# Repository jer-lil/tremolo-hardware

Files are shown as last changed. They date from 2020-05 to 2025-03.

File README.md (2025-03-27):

This is the hardware (PCB, MCAD) design for a tremolo pedal for guitar (or bass, synth, tonewheel organ, whatever you like). 
The firmware is here: https://github.com/jer-lil/tremolo-firmware/tree/main

This tremolo packs a lot of features into a very small (Hammond 125B, 65x120mm) enclosure.
Features include:

- All analog signal path
- Full stereo, with dedicated 1/4" jacks
- Harmonic tremolo
  - Continually adjustable LFO phase, allowing for sounds between mono/stereo/harmonic not found in other tremolo pedals (that I've discovered, please let me know if you know of any)
- Envelope control
  - The louder you play, the faster the tremolo goes. Or slower. Or stronger. Or the triangle wave warps towards a sawtooth. You decide.
- Expression pedal control
- Tap Tempo
  - Optional external tap signal
- "Ramp" mode, allowing user to ramp the rate up or down using a footswitch
- MIDI control

Note that at the time of writing, this project is still in progress.
As such, I have not been focusing on public documentation. If you have questions, please reach out.

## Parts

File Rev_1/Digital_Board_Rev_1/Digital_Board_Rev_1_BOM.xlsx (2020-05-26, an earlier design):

Id | Designator | Package | MPN | Quantity | Designation | Supplier and ref | _1
1 | J1 | MF_Connectors-MICROUSB-RIGHT |  | 1 | USB_MICRO_RIGHT
2 | U1 | MF_IC_Digital-SSOP16 |  | 1 | FT230XS-R
3 | REF**,REF**,C12,C21,C20,C19,C18,C17,C16,C14,C13,C9,C8,C7,C3,C2 | MF_Passives-C0402 |  | 16 | 0.1uF
4 | GND | MF_Connectors-PTH_2.54MM_01X02 |  | 1 | VAL**
5 | DEPTH,TRIM,SUBDIV,OFFSET,SHAPE,RATE | MF_Passives-TC33 | TC33X-2-103E | 6 | POTENTIOMETER_10K_TC33
6 | JP8,JP7,JP6,JP5,JP4,JP3,JP2,JP1,JP14,JP13,JP12,JP11,JP10,JP9 | SolderJumper-2_P1.3mm_Bridged_Pad1.0x1.5mm |  | 14 | SolderJumper_2_Bridged
7 | J22,J13,SW1,SW2,J17,PWM | MF_Connectors-PTH_2.54MM_01X02 |  | 6 | CON_01X02_PTH_2.54MM
8 | H4,H3,H2,H1 | MountingHole_3.2mm_M3 |  | 4 | MountingHole_Pad
9 | C24,C23,C22,C15 | MF_Passives-C0402 |  | 4 | 100n
10 | J21 | BarrelJack_CUI_PJ-063AH_Horizontal_CircularHoles |  | 1 | Barrel_Jack
11 | U15,U14 | SOP-4_3.8x4.1mm_P2.54mm |  | 2 | CPC1017N
12 | J20 | Jack_0.25in_TRS_Switched |  | 1 | AudioJack3_Switch
13 | U13 | LQFP-64_10x10mm_P0.5mm | STM32F030RCT6TR | 1 | STM32F030RCTx
14 | U12,U11,U8,U7 | Luna_NSL-32 |  | 4 | NSL-32
15 | U10,U9,U6,U5 | MF_Discrete_Semiconductor-SOT-23-3 |  | 4 | NPN_BJTMMBT3904_SOT-23-3
16 | U4,U3 | TSSOP-14-1EP_4.4x5mm_P0.65mm |  | 2 | MCP42050
17 | U2 | MF_IC_Power-SOT-223-3 |  | 1 | NCP1117LPST33T3G
18 | RESET | MF_Switches-TACT4.2MM |  | 1 | TACT_4.2MM
19 | BYPASS,TAP | MF_Switches-TACT6MM |  | 2 | TACT_6MM
20 | SW2 | SW_DIP_SPSTx02_Slide_9.78x7.26mm_W7.62mm_P2.54mm |  | 1 | SW_DIP_x02
21 | SW1 | SW_DIP_SPSTx04_Slide_9.78x12.34mm_W7.62mm_P2.54mm |  | 1 | SW_DIP_x04
22 | RV6,RV5,RV4,RV3,RV2,RV1 | Potentiometer_Alpha_RD901F-40-00D_Single_Vertical_CircularHoles |  | 6 | 10k
23 | R29,R28 | MF_Passives-R0402 |  | 2 | 47
24 | R27,R26,R25 | MF_Passives-R0402 |  | 3 | 100
25 | R18 | MF_Passives-R0603 |  | 1 | 0
26 | R17 | MF_Passives-R0402 |  | 1 | 10k
27 | R16,R15,R10,R9 | MF_Passives-R0603 |  | 4 | 10k
28 | R14,R13,R12,R11,R8,R7,R6,R5 | MF_Passives-R0603 |  | 8 | 100
29 | R4 | MF_Passives-R0402 |  | 1 | 470
30 | R3,R2 | MF_Passives-R0402 |  | 2 | 330
31 | R1 | MF_Passives-R0402 |  | 1 | 560
32 | GPIO,SWD,UART | MF_Connectors-PTH_2.54MM_01X06 |  | 3 | CON_01X06_PTH_2.54MM
33 | J14 | MF_Connectors-PTH_2.54MM_01X04 |  | 1 | CON_01X04_PTH_2.54MM
34 | AIN,Digipot_2_1,Digipot_2_0,Digipot_1_1,Digipot_1_0 | MF_Connectors-PTH_2.54MM_01X03 |  | 5 | CON_01X03_PTH_2.54MM
35 | J9,J8,J7,J6 | MF_Connectors-PTH_2.54MM_01X02 |  | 4 | Conn_01x02_Male
36 | D13,D1 | MF_Discrete_Semiconductor-SMA |  | 2 | DIODES_B140_SMA
37 | LED2,D9,D8,D7,D6 | MF_LEDs-LED0805 |  | 5 | LED_SINGLE-0805-RED
38 | LED1 | MF_LEDs-LED0805 |  | 1 | LED_SINGLE-0805-GREEN
39 | D10 | MF_LEDs-PLCC4 |  | 1 | LED_RGB_CA_PLCC4
40 | 3V3,D4,D3,VIN | MF_LEDs-LED0603 |  | 4 | LED_SINGLE-0603-GREEN
41 | C11,C1 | MF_Passives-C0402 |  | 2 | 1uF
42 | C10 | MF_Passives-C0402 |  | 1 | 10n
43 | C6,C5,C4 | MF_Passives-C1206 |  | 3 | 10uF

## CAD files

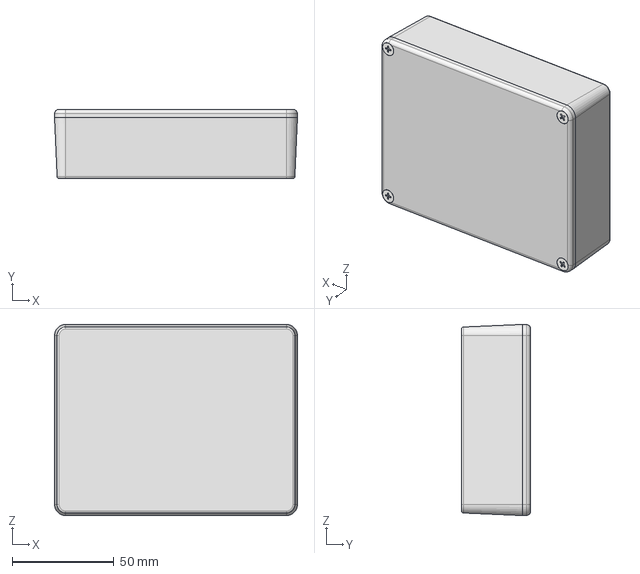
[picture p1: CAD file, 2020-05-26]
3D_Models/1590BB.stp
119.5 x 34.0 x 94.0 mm

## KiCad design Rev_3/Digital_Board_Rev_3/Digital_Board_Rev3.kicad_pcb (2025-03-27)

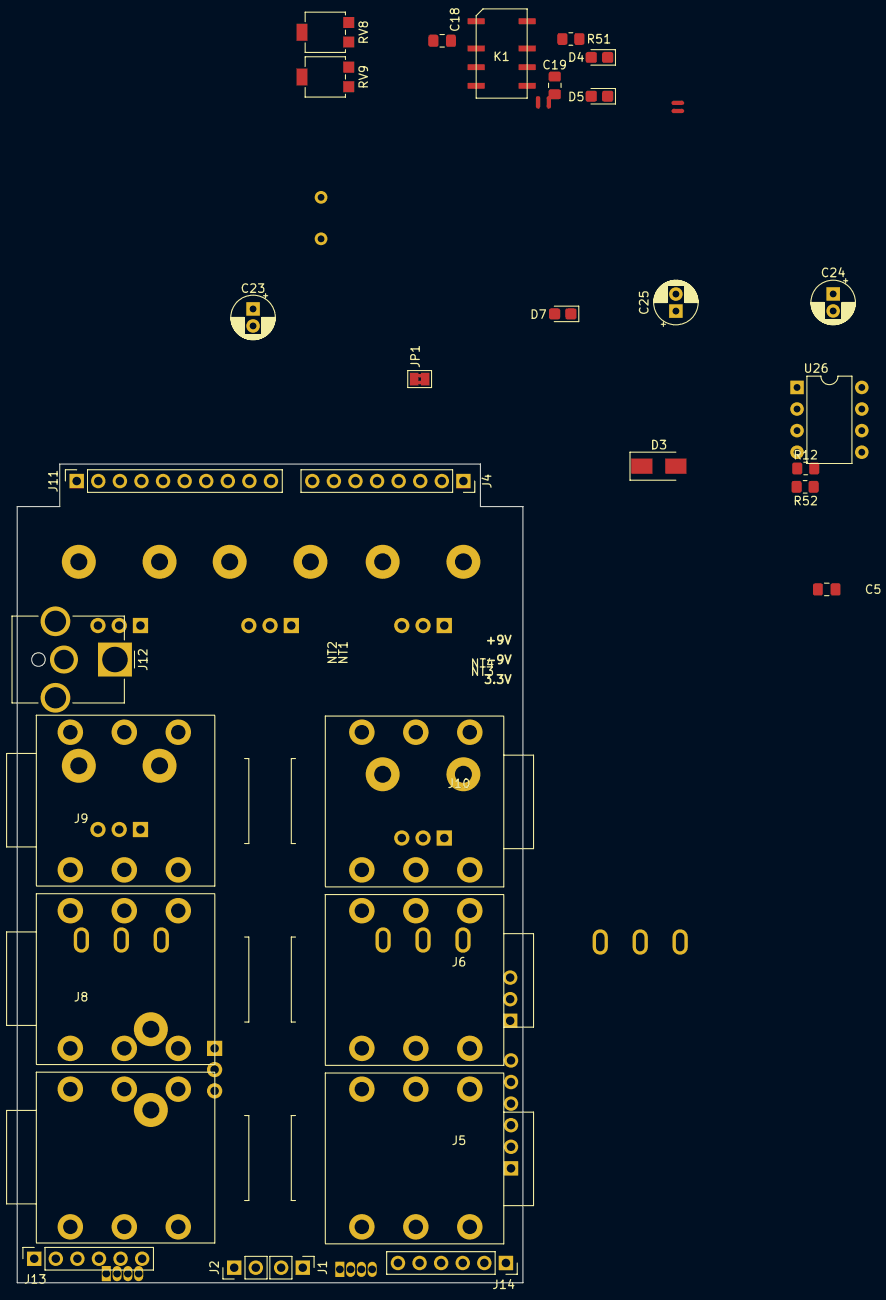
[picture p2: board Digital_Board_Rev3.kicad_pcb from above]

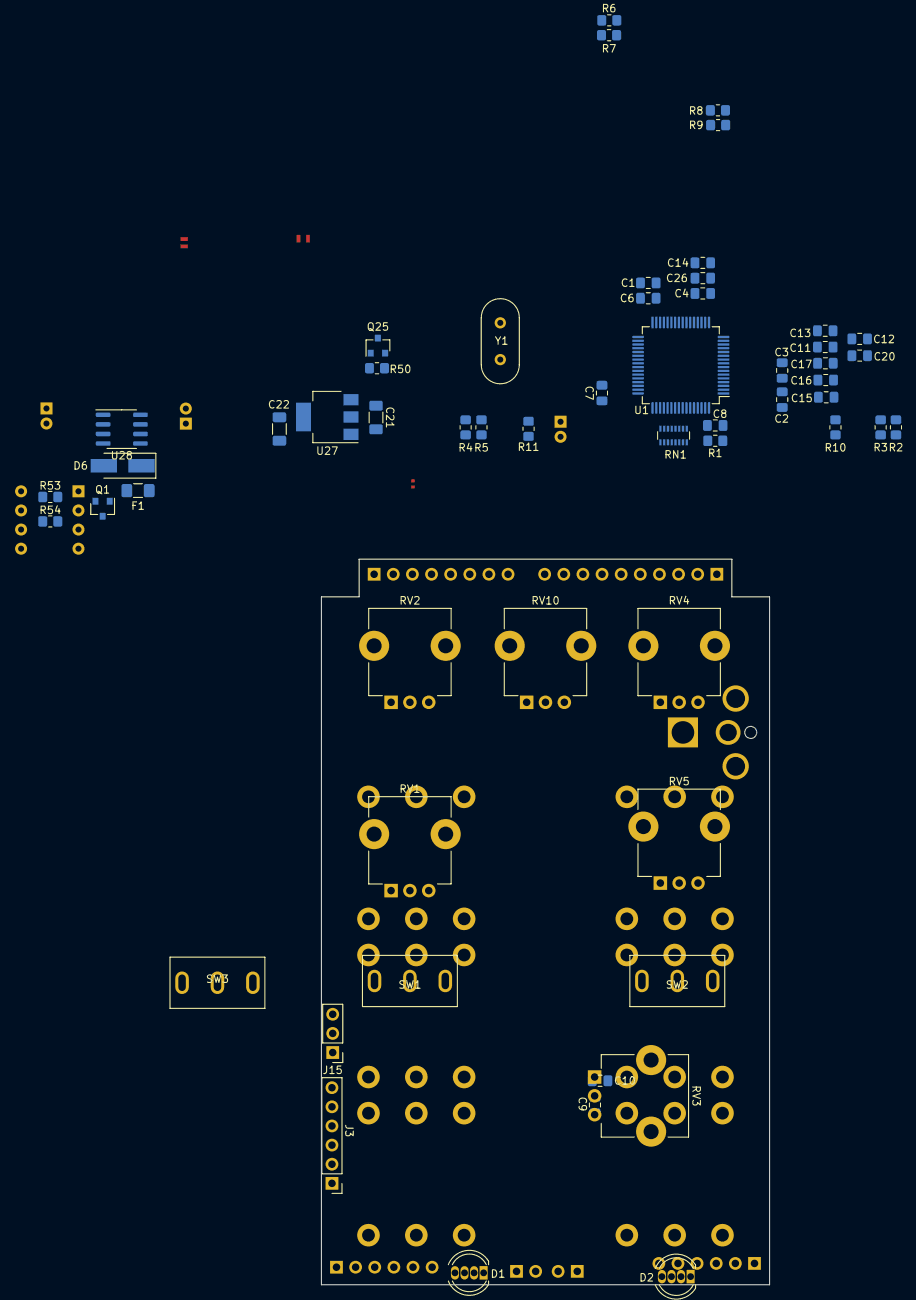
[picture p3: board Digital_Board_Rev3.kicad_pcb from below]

Board: 4 copper layers, 59.5 x 96.3 mm, 91 parts (56 on the bottom side), 94 nets, no tracks yet.

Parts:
C1: 4.7u; C_0805_2012Metric_Pad1.18x1.45mm_HandSolder
C2, C3: 18p; C_0805_2012Metric_Pad1.18x1.45mm_HandSolder
C4, C5, C6, C7, C8, C16, C17, C20: 100n; C_0805_2012Metric_Pad1.18x1.45mm_HandSolder
C9: 10n; C_0805_2012Metric_Pad1.18x1.45mm_HandSolder
C10: 1u; C_0805_2012Metric_Pad1.18x1.45mm_HandSolder
C11, C12, C13, C14, C15, C26: 100nF; C_0805_2012Metric_Pad1.18x1.45mm_HandSolder
C18, C19: 470n; C_0805_2012Metric_Pad1.18x1.45mm_HandSolder
C21, C22: 10u; C_1206_3216Metric_Pad1.33x1.80mm_HandSolder
C23, C24, C25: 100uF; CP_Radial_D5.0mm_P2.00mm
D1, D2: LED_RGBA; LED_D5.0mm-4_RGB
D3: B120-E3; D_SMA
D4, D5, D7: LED_Small; LED_0805_2012Metric_Castellated
D6: D_Zener; D_SMA_Handsoldering
F1: Polyfuse; Fuse_1206_3216Metric_Pad1.42x1.75mm_HandSolder
J1, J2: Conn_01x02_Male; PinHeader_1x02_P2.54mm_Vertical
J3: Conn_01x06_Male; PinHeader_1x06_P2.54mm_Vertical
J4: Conn_01x08_Female; PinSocket_1x08_P2.54mm_Vertical
J5, J6, J7, J8, J9, J10: AudioJack3_Switch; Jack_0.25in_TRS_Switched
J11: Conn_01x10_Female; PinSocket_1x10_P2.54mm_Vertical
J12: Barrel_Jack; BarrelJack_CUI_PJ-063AH_Horizontal_CircularHoles
J13, J14: Conn_01x06_Female; PinSocket_1x06_P2.54mm_Vertical
J15: Conn_01x03_Male; PinHeader_1x03_P2.54mm_Vertical
JP1: Jumper; SolderJumper-2_P1.3mm_Bridged2Bar_Pad1.0x1.5mm
K1: IM05; Relay_DPDT_NL_TE_IM05GR
NT1, NT2, NT3, NT4: Net-Tie_2; NetTie-2_SMD_Pad0.5mm
Q1: BSS83P; SOT-23
Q25: MMBT3904; SOT-23
R1, R8: 10k; R_0805_2012Metric_Pad1.20x1.40mm_HandSolder
R2, R3, R4, R5, R10, R11: 330; R_0805_2012Metric_Pad1.20x1.40mm_HandSolder
R6, R7, R12, R51: 1k; R_0805_2012Metric_Pad1.20x1.40mm_HandSolder
R9: 19.1k; R_0805_2012Metric_Pad1.20x1.40mm_HandSolder
R50: 2.2k; R_0805_2012Metric_Pad1.20x1.40mm_HandSolder
R52: 470; R_0805_2012Metric_Pad1.20x1.40mm_HandSolder
R53, R54: 630; R_0805_2012Metric_Pad1.20x1.40mm_HandSolder
RN1: R_Pack08; R_Array_Convex_8x0602
RV1, RV2, RV3, RV4, RV5, RV10: R_POT_TRIM; Potentiometer_9MM
RV8, RV9: 100k; Potentiometer_Bourns_3314G_Vertical
SW1, SW2, SW3: SW_SPDT_MSM; SW_Toggle_SPDT
U1: STM32F303R6Tx; LQFP-64_10x10mm_P0.5mm
U26: TLP222A-2; DIP-8_W7.62mm
U27: NCP1117-3.3_SOT223; SOT-223-3_TabPin2
U28: TC7662Bx0A; SOIC-8_3.9x4.9mm_P1.27mm
Y1: 8MHz; Crystal_HC49-U_Vertical

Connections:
+3V3: C1.1, C4.1, C6.1, C7.1, C8.1, C9.1, C10.1, C22.1, D1.4, D2.4, J3.1, J9.R, J11.9, R6.2, R52.1, RV1.3, RV2.3, RV3.3, RV4.3, RV5.3, RV10.3, U1.13, U1.19, U1.32, U1.48, U1.64, U27.2
+9V: C21.1, C23.1, D3.1, D6.1, F1.1, J4.7, K1.1, R51.1, U27.3, U28.1, U28.8
-9V: C25.2, J4.4, R12.2, U28.5
/Audio Jacks/CH1_OUT: J8.T, RV8.2
/Audio Jacks/CH1_OUT_PRE: C18.1, RV8.1, U26.8
/Audio Jacks/CH2_OUT: J7.T, RV9.2
/Audio Jacks/CH2_OUT_PRE: C19.1, RV9.1, U26.6
/BYP: J1.2, U1.44
/CH1_BYP: J11.2, K1.2
/CH1_EFF: J11.3, K1.4
/CH1_IN: J5.T, J6.TN, J11.1
/CH1_SW: J5.SN, U1.51
/CH2_BYP: J4.2, K1.7
/CH2_EFF: J4.3, K1.5
/CH2_IN: J4.1, J6.T
/CH2_SW: J6.SN, U1.52
/DEPTH: C12.1, RV2.2, U1.15
/DIP1: J11.8, U1.26
/DIP2: J11.7, U1.27
/DIP3: J11.6, U1.28
/DIP4: J11.5, U1.43
/ENV_MODE_1: SW3.3, U1.34
/ENV_MODE_2: SW3.1, U1.35
/EXP: C16.1, R8.2, R9.1, U1.9
/EXP_SW: J9.SN, U1.42
/HARM_MODE_1: SW1.3, U1.62
/HARM_MODE_2: SW1.1, U1.29
/LED1_B: RN1.6, U1.53
/LED1_G: RN1.5, U1.54
/LED1_R: RN1.4, U1.56
/LED2_B: RN1.3, U1.57
/LED2_G: RN1.2, U1.58
/LED2_R: RN1.1, U1.59
/LEDs/B1_R: D1.3, RN1.11
/LEDs/B2_R: D2.3, RN1.14
/LEDs/G1_R: D1.2, RN1.12
/LEDs/G2_R: D2.2, RN1.15
/LEDs/R1_R: D1.1, RN1.13
/LEDs/R2_R: D2.1, RN1.16
/MUTE1: R53.2, U1.2
/MUTE2: R54.2, U1.3
/NRST: C5.1, J3.5, U1.7
/OFFSET: C14.1, RV4.2, U1.17
/OSC1: C2.2, U1.5, Y1.2
/OSC2: C3.2, U1.6, Y1.1
/PAN_MODE_1: SW2.3, U1.30
/PAN_MODE_2: SW2.1, U1.33
/PWM1: R2.1, U1.22
/PWM2: R3.1, U1.20
/PWM3: R4.1, U1.39
/PWM4: R5.1, U1.40
/PWM_OUT_1: J13.1, R2.2
/PWM_OUT_2: J13.3, R3.2
/PWM_OUT_3: J14.2, R4.2
/PWM_OUT_4: J14.4, R5.2
/PWM_OUT_VOL_1: J13.5, R10.2
/PWM_OUT_VOL_2: J14.6, R11.2
/PWM_RTN_1: J13.2, NT1.1
/PWM_RTN_2: J13.4, NT2.1
/PWM_RTN_3: J14.1, NT3.1
/PWM_RTN_4: J14.3, NT4.1
/PWM_VOL_1: R10.1, U1.21
/PWM_VOL_2: R11.1, U1.55
/RATE: C11.1, RV1.2, U1.14
/RLY_SET: R50.2, U1.50
/SHAPE: C13.1, RV3.2, U1.16
/SUBDIV: C15.1, RV5.2, U1.8
/SWCLK: J3.2, U1.49
/SWDIO: J3.4, U1.46
/TAP: J2.2, U1.45
/TAP_EXT: R7.2, U1.37
/TRIM1: C17.1, J4.6, U1.10
/TRIM2: C20.1, J4.5, U1.11
/UART_RX: J15.2, U1.25
/UART_TX: J15.3, U1.24
/VOL: C26.1, RV10.2, U1.23
GNDA: J4.8, J5.S, J6.S, J7.S, J8.S, J11.10, JP1.2, RV8.3, RV9.3, U26.5, U26.7
GNDD: C1.2, C2.1, C3.1, C4.2, C5.2, C6.2, C7.2, C8.2, C9.2, C10.2, C11.2, C12.2, C13.2, C14.2, C15.2, C16.2, C17.2, C20.2, C21.2, C22.2, C23.2, C25.1, C26.2, D4.1, D5.1, D6.2, D7.2, J1.1, J2.1, J3.3, J9.S, J11.4, J12.2, J15.1, JP1.1, NT1.2, NT2.2, NT3.2, NT4.2, Q1.1, Q25.2, R1.1, R9.2, RV1.1, RV2.1, RV3.1, RV4.1, RV5.1, RV10.1, SW1.2, SW2.2, SW3.2, U1.12, U1.18, U1.31, U1.47, U1.63, U26.2, U26.4, U27.1, U28.3
unnamed: C18.2, K1.3
unnamed: C19.2, K1.6
unnamed: C24.1, U28.2
unnamed: C24.2, U28.4
unnamed: D3.2, K1.8, Q25.3
unnamed: D4.2, R51.2
unnamed: D5.2, R52.2
unnamed: D7.1, R12.1
unnamed: F1.2, Q1.2
unnamed: J9.T, R8.1
unnamed: J10.T, R6.1, R7.1
unnamed: J12.1, Q1.3
unnamed: Q25.1, R50.1
unnamed: R1.2, U1.60
unnamed: R53.1, U26.1
unnamed: R54.1, U26.3

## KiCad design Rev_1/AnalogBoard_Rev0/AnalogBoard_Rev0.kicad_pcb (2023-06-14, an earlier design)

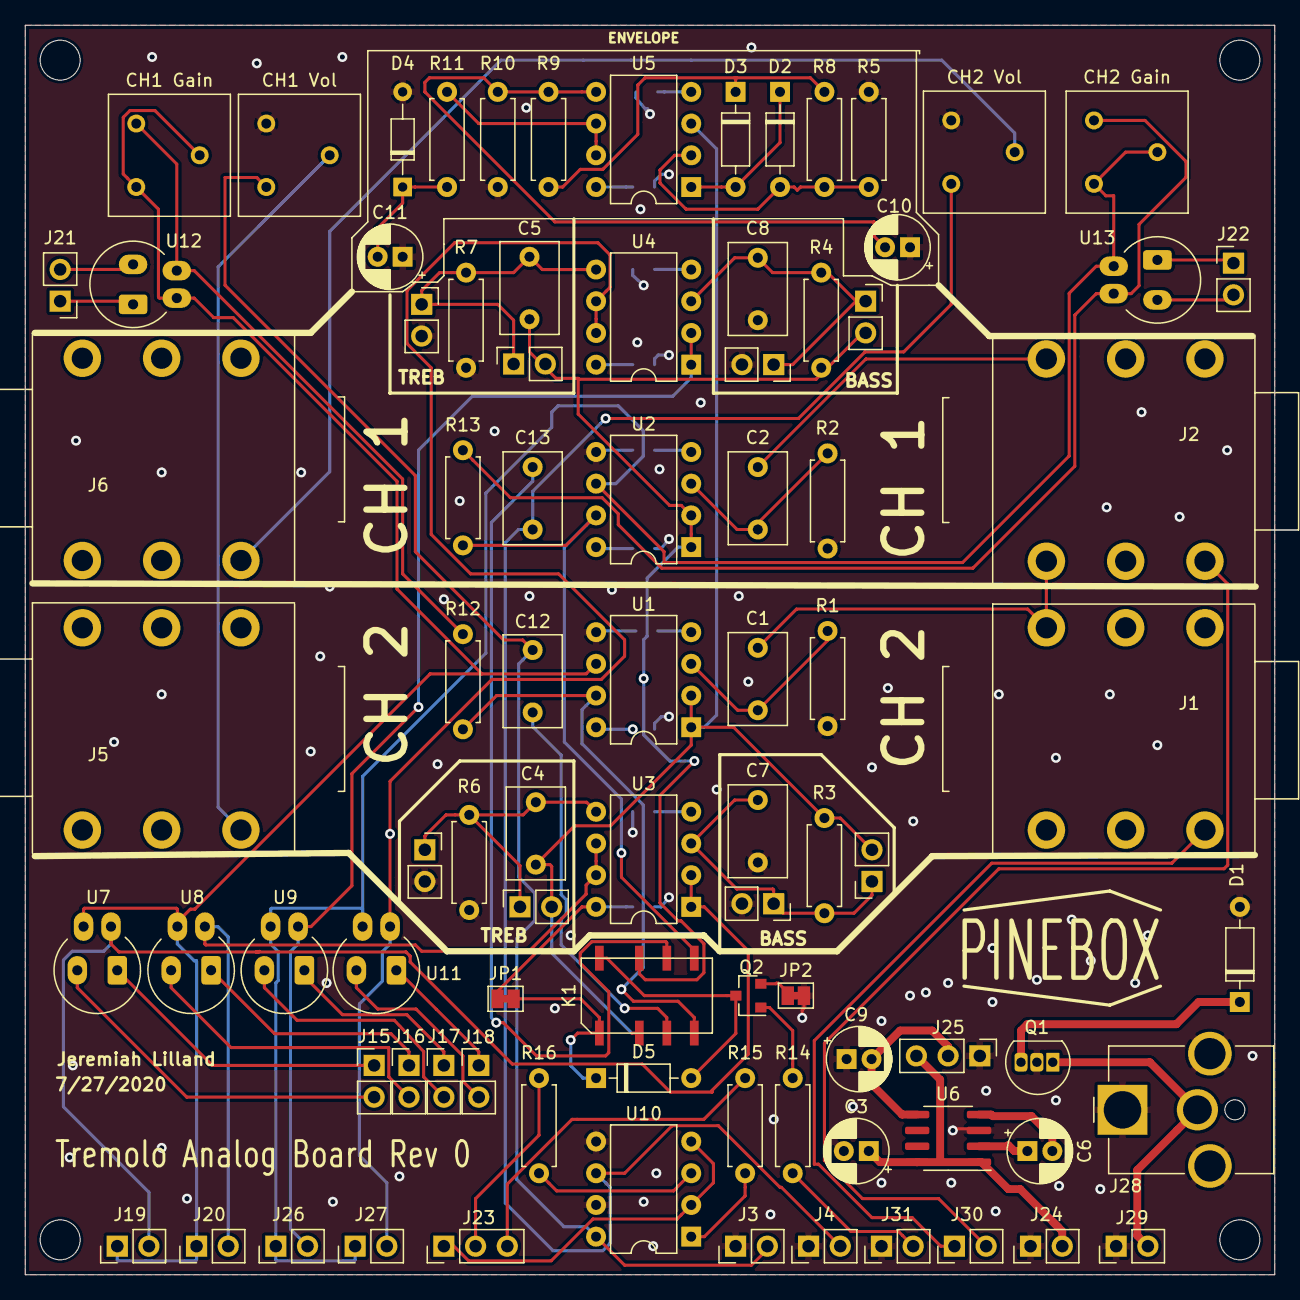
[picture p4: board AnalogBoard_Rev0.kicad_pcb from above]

Board: 4 copper layers, 100.1 x 100.1 mm, 101 parts (0 on the bottom side), 62 nets.

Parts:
C1, C2: 47n; C_Rect_L7.2mm_W4.5mm_P5.00mm_FKS2_FKP2_MKS2_MKP2
C3, C6, C9: 100uF; CP_Radial_D5.0mm_P2.00mm
C4, C5, C7, C8: 1n; C_Rect_L7.2mm_W4.5mm_P5.00mm_FKS2_FKP2_MKS2_MKP2
C10: 4.7u; CP_Radial_D5.0mm_P2.00mm
C11: 47u; CP_Radial_D5.0mm_P2.00mm
C12, C13: 470n; C_Rect_L7.2mm_W4.5mm_P5.00mm_FKS2_FKP2_MKS2_MKP2
C14, C15, C16, C17, C18, C19, C20, C21, C22, C23: 100n; C_0603_1608Metric_Pad1.05x0.95mm_HandSolder
CH1 Gain, CH1 Vol, CH2 Gain, CH2 Vol: 50k; Potentiometer_Bourns_3386F_Vertical
D1: 10.2; D_DO-35_SOD27_P7.62mm_Horizontal
D2, D3: 1N914; D_DO-35_SOD27_P7.62mm_Horizontal
D4: D_Zener; D_DO-34_SOD68_P7.62mm_Horizontal
D5: B120-E3; D_DO-35_SOD27_P7.62mm_Horizontal
H1, H2, H3, H4: MountingHole; MountingHole_3.2mm_M3
J1, J2, J5, J6: AudioJack3_Switch; Jack_0.25in_TRS_Switched
J3, J4, J15, J16, J17, J18, J19, J20, J21, J22, J24, J26, J27, J29, J30, J31: Conn_01x02_Male; PinHeader_1x02_P2.54mm_Vertical
J7, J8, J9, J10, J11, J12, J13, J14: Conn_01x02_Female; PinSocket_1x02_P2.54mm_Vertical
J23, J25: Conn_01x03_Male; PinHeader_1x03_P2.54mm_Vertical
J28: Barrel_Jack_MountingPin; BarrelJack_CUI_PJ-063AH_Horizontal_CircularHoles
JP1, JP2: JMP_NC; SolderJumper-2_P1.3mm_Bridged_Pad1.0x1.5mm
K1: IM05; Relay_DPDT_NL_TE_IM05GR
Q1: Q_PMOS_DGS; TO-92L_Inline
Q2: MMBT3904; SOT-23
R1, R2: 1M; R_Axial_DIN0207_L6.3mm_D2.5mm_P7.62mm_Horizontal
R3, R4, R6, R7: 470k; R_Axial_DIN0207_L6.3mm_D2.5mm_P7.62mm_Horizontal
R5: 3.3k; R_Axial_DIN0207_L6.3mm_D2.5mm_P7.62mm_Horizontal
R8: 100k; R_Axial_DIN0207_L6.3mm_D2.5mm_P7.62mm_Horizontal
R9: 10k; R_Axial_DIN0207_L6.3mm_D2.5mm_P7.62mm_Horizontal
R10: 47k; R_Axial_DIN0207_L6.3mm_D2.5mm_P7.62mm_Horizontal
R11, R12, R13: 1k; R_Axial_DIN0207_L6.3mm_D2.5mm_P7.62mm_Horizontal
R14: 4.7k; R_Axial_DIN0207_L6.3mm_D2.5mm_P7.62mm_Horizontal
R15, R16: 630; R_Axial_DIN0207_L6.3mm_D2.5mm_P7.62mm_Horizontal
U1, U2, U3, U4, U5: OPA2134; DIP-8_W7.62mm
U6: TC7662Bx0A; SOIC-8_3.9x4.9mm_P1.27mm
U7, U8, U9, U11, U12, U13: NSL-32; Luna_NSL-32_Vertical
U10: TLP222A-2; DIP-8_W7.62mm

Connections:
+9V: C3.1, C14.2, C16.2, C18.2, C20.2, C22.2, D1.1, J24.2, J25.3, JP1.2, Q1.3, U1.8, U2.8, U3.8, U4.8, U5.8, U6.1, U6.8
-9V: C9.2, C15.1, C17.1, C19.1, C21.1, C23.1, J25.2, U1.4, U2.4, U3.4, U4.4, U5.4, U6.5
/ENV_OUT: C11.2, D4.1, R11.2
/IN1: C1.2, J1.T, J2.TN
/IN2: C2.2, J2.T
/LDRA_1: J19.2, U3.1, U3.2, U7.4
/LDRA_2: CH1 Gain.1, CH1 Gain.2, J19.1, J20.1, U1.6, U7.3, U8.3, U12.4
/LDRB_1: J20.2, U3.6, U3.7, U8.4
/LDRC_1: J26.2, U4.1, U4.2, U9.4
/LDRC_2: CH2 Gain.1, CH2 Gain.2, J26.1, J27.1, U2.6, U9.3, U11.3, U13.4
/LDRD_1: J27.2, U4.6, U4.7, U11.4
/MUTE1: J23.3, R15.1
/MUTE2: J23.2, R16.1
/OUT1: CH1 Vol.2, J5.T
/OUT2: CH2 Vol.2, J6.T
/PWR_IN: J28.2, J29.2, Q1.1
/RLY_SET: J31.2, R14.1
/SW_STREO_1: J1.SN, J30.1
/SW_STREO_2: J2.SN, J30.2
GND: C3.2, C7.1, C8.1, C9.1, C10.1, C11.1, C14.1, C15.2, C16.1, C17.2, C18.1, C19.2, C20.1, C21.2, C22.1, C23.2, CH1 Vol.3, CH2 Vol.3, D1.2, D4.2, J3.1, J4.1, J11.2, J12.2, J13.2, J14.2, J24.1, J25.1, J28.1, J28.MP, J29.1, J31.1, JP2.1, Q1.2, R1.1, R2.1, R5.2, R6.1, R7.1, R10.2, U1.5, U2.5, U6.3, U10.5, U10.7
GNDD: J23.1, U10.2, U10.4
unnamed: C1.1, R1.2, U1.3
unnamed: C2.1, R2.2, U2.3
unnamed: C4.1, J8.1, J11.1, R6.2, U3.5
unnamed: C4.2, J7.2, J8.2, K1.2, R3.1, U1.1, U1.2, U5.3
unnamed: C5.1, J10.1, J12.1, R7.2, U4.5
unnamed: C5.2, J9.2, J10.2, K1.7, R4.1, U2.1, U2.2
unnamed: C6.1, U6.2
unnamed: C6.2, U6.4
unnamed: C7.2, J7.1, J13.1, R3.2, U3.3
unnamed: C8.2, J9.1, J14.1, R4.2, U4.3
unnamed: C10.2, R9.2, R10.1, U5.5
unnamed: C12.1, CH1 Vol.1, J3.2, U10.8
unnamed: C12.2, K1.3
unnamed: C13.1, CH2 Vol.1, J4.2, U10.6
unnamed: C13.2, K1.6
unnamed: D2.1, D3.2, U5.1
unnamed: D2.2, R5.1, R8.1, U5.2
unnamed: D3.1, R8.2, R9.1
unnamed: D5.1, JP1.1, K1.1
unnamed: D5.2, K1.8, Q2.3
unnamed: J15.1, U7.1
unnamed: J15.2, U7.2
unnamed: J16.1, U8.1
unnamed: J16.2, U8.2
unnamed: J17.1, U9.1
unnamed: J17.2, U9.2
unnamed: J18.1, U11.1
unnamed: J18.2, U11.2
unnamed: J21.1, U12.1
unnamed: J21.2, U12.2
unnamed: J22.1, U13.1
unnamed: J22.2, U13.2
unnamed: JP2.2, Q2.2
unnamed: K1.4, R12.2, U1.7
unnamed: K1.5, R13.2, U2.7
unnamed: Q2.1, R14.2
unnamed: R11.1, U5.6, U5.7
unnamed: CH1 Gain.3, R12.1, U12.3
unnamed: CH2 Gain.3, R13.1, U13.3
unnamed: R15.2, U10.1
unnamed: R16.2, U10.3

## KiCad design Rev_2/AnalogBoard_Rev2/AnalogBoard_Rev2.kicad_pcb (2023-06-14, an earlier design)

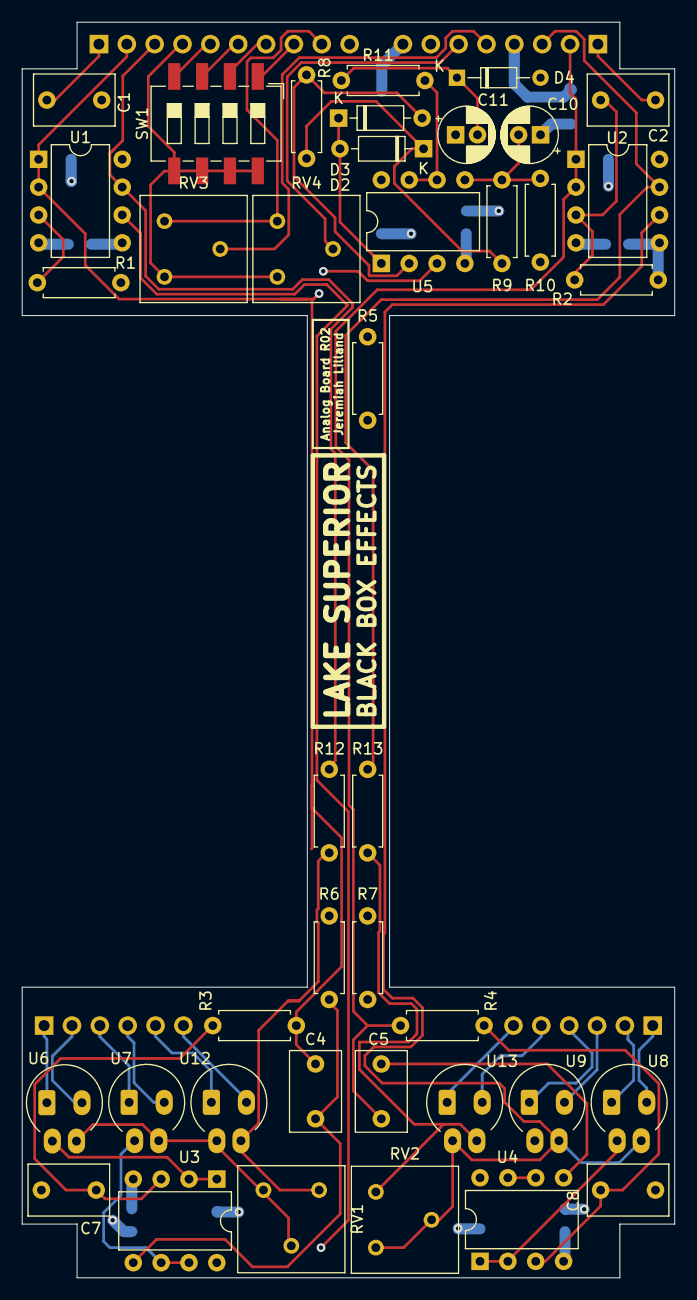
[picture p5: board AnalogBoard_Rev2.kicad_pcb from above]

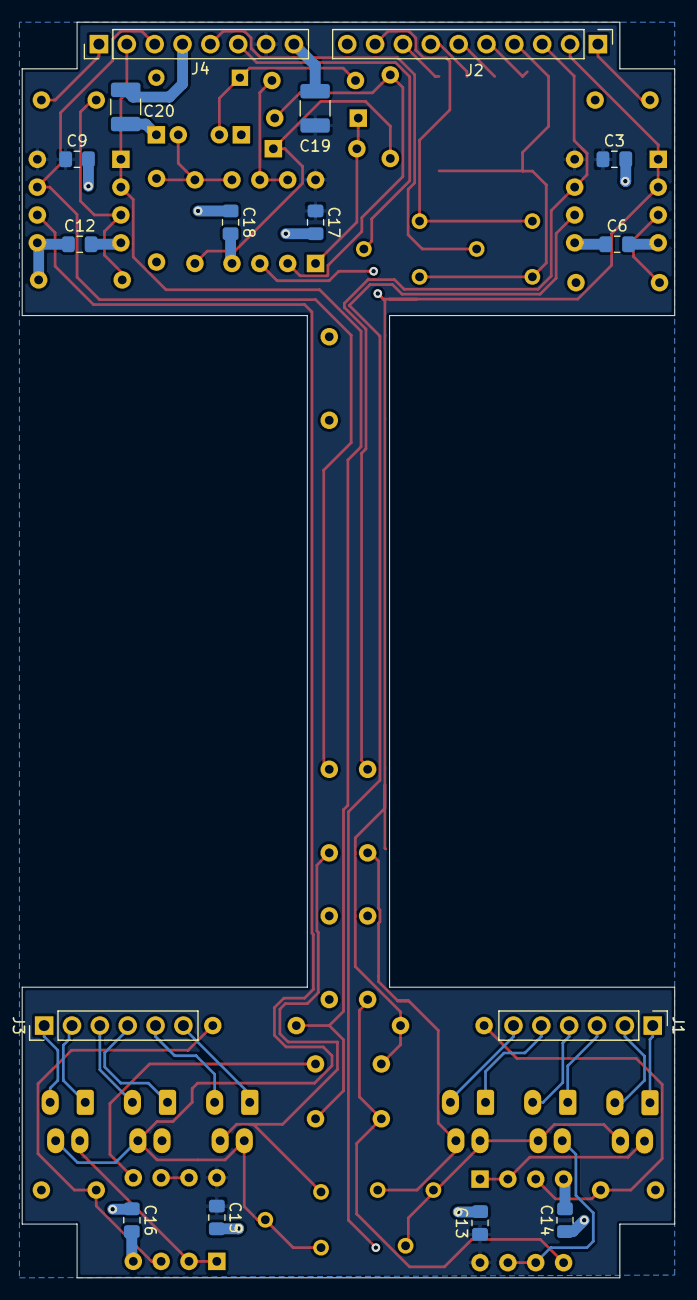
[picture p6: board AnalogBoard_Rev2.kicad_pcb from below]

Board: 4 copper layers, 59.5 x 114.5 mm, 56 parts (16 on the bottom side), 49 nets.

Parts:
C1, C2: 47n; C_Rect_L7.2mm_W4.5mm_P5.00mm_FKS2_FKP2_MKS2_MKP2
C3, C6, C9, C12, C13, C14, C15, C16, C17, C18: 100n; C_0805_2012Metric_Pad1.18x1.45mm_HandSolder
C4, C5, C7, C8: 1n; C_Rect_L7.2mm_W4.5mm_P5.00mm_FKS2_FKP2_MKS2_MKP2
C10: 4.7u; CP_Radial_D5.0mm_P2.00mm
C11: 47u; CP_Radial_D5.0mm_P2.00mm
C19, C20: 10u; C_1210_3225Metric_Pad1.33x2.70mm_HandSolder
D2, D3: 1N914; D_DO-35_SOD27_P7.62mm_Horizontal
D4: D_Zener; D_DO-34_SOD68_P7.62mm_Horizontal
J1, J3: Conn_01x06_Male; PinHeader_1x06_P2.54mm_Vertical
J2: Conn_01x10_Male; PinHeader_1x10_P2.54mm_Vertical
J4: Conn_01x08_Male; PinHeader_1x08_P2.54mm_Vertical
R1, R2: 1M; R_Axial_DIN0207_L6.3mm_D2.5mm_P7.62mm_Horizontal
R3, R4, R6, R7: 470k; R_Axial_DIN0207_L6.3mm_D2.5mm_P7.62mm_Horizontal
R5: 3.3k; R_Axial_DIN0207_L6.3mm_D2.5mm_P7.62mm_Horizontal
R8: 100k; R_Axial_DIN0207_L6.3mm_D2.5mm_P7.62mm_Horizontal
R9: 10k; R_Axial_DIN0207_L6.3mm_D2.5mm_P7.62mm_Horizontal
R10: 47k; R_Axial_DIN0207_L6.3mm_D2.5mm_P7.62mm_Horizontal
R11, R12, R13: 1k; R_Axial_DIN0207_L6.3mm_D2.5mm_P7.62mm_Horizontal
RV1, RV2, RV3, RV4: 50k; Potentiometer_Bourns_3386F_Vertical
SW1: SW_DIP_x04; SW_DIP_SPSTx04_Slide_6.7x11.72mm_W8.61mm_P2.54mm_LowProfile
U1, U2, U3, U4, U5: OPA2134; DIP-8_W7.62mm
U6, U7, U8, U9, U12, U13: NSL-32; Luna_NSL-32_Vertical

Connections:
+3V3: J2.9, RV3.3, RV4.3
+9V: C3.1, C9.1, C13.1, C15.1, C17.1, C19.1, J4.7, U1.8, U2.8, U3.8, U4.8, U5.8
-9V: C6.2, C12.2, C14.2, C16.2, C18.2, C20.2, J4.4, U1.4, U2.4, U3.4, U4.4, U5.4
/CH1_BYP: C4.2, J2.2, R3.1, U1.1, U1.2, U5.3
/CH1_EFF: J2.3, R12.2, U1.7
/CH2_BYP: C5.2, J4.2, R4.1, U2.1, U2.2
/CH2_EFF: J4.3, R13.2, U2.7
/DIP1: J2.8, SW1.1
/DIP2: J2.7, SW1.2
/DIP3: J2.6, SW1.3
/DIP4: J2.5, SW1.4
/ENV_OUT: C11.2, D4.1, R11.2
/IN1: C1.2, J2.1
/IN2: C2.2, J4.1
/LDRA_1: U3.1, U3.2, U6.4
/LDRA_2: RV1.1, RV1.2, U1.6, U6.3, U7.3, U12.4
/LDRB_1: U3.6, U3.7, U7.4
/LDRC_1: U4.1, U4.2, U8.4
/LDRC_2: RV2.1, RV2.2, U2.6, U8.3, U9.3, U13.4
/LDRD_1: U4.6, U4.7, U9.4
/PWM_1: J1.1, U6.1
/PWM_1_RTN: J1.2, U6.2
/PWM_2: J1.3, U7.1
/PWM_2_RTN: J1.4, U7.2
/PWM_3: J3.2, U8.1
/PWM_3_RTN: J3.1, U8.2
/PWM_4: J3.4, U9.1
/PWM_4_RTN: J3.3, U9.2
/PWM_VOL1: J1.5, U12.1
/PWM_VOL1_RTN: J1.6, U12.2
/PWM_VOL2: J3.6, U13.1
/PWM_VOL2_RTN: J3.5, U13.2
/TRIM_1: J4.5, RV3.2
/TRIM_2: J4.6, RV4.2
GND: C3.2, C6.1, C7.1, C8.1, C9.2, C10.1, C11.1, C12.1, C13.2, C14.1, C15.2, C16.1, C17.2, C18.1, C19.2, C20.1, D4.2, J2.10, J4.8, R1.1, R2.1, R5.2, R6.1, R7.1, R10.2, U1.5, U2.5
GNDD: J2.4, RV3.1, RV4.1, SW1.5, SW1.6, SW1.7, SW1.8
unnamed: C1.1, R1.2, U1.3
unnamed: C2.1, R2.2, U2.3
unnamed: C4.1, R6.2, U3.5
unnamed: C5.1, R7.2, U4.5
unnamed: C7.2, R3.2, U3.3
unnamed: C8.2, R4.2, U4.3
unnamed: C10.2, R9.2, R10.1, U5.5
unnamed: D2.1, D3.2, U5.1
unnamed: D2.2, R5.1, R8.1, U5.2
unnamed: D3.1, R8.2, R9.1
unnamed: R11.1, U5.6, U5.7
unnamed: R12.1, RV1.3, U12.3
unnamed: R13.1, RV2.3, U13.3

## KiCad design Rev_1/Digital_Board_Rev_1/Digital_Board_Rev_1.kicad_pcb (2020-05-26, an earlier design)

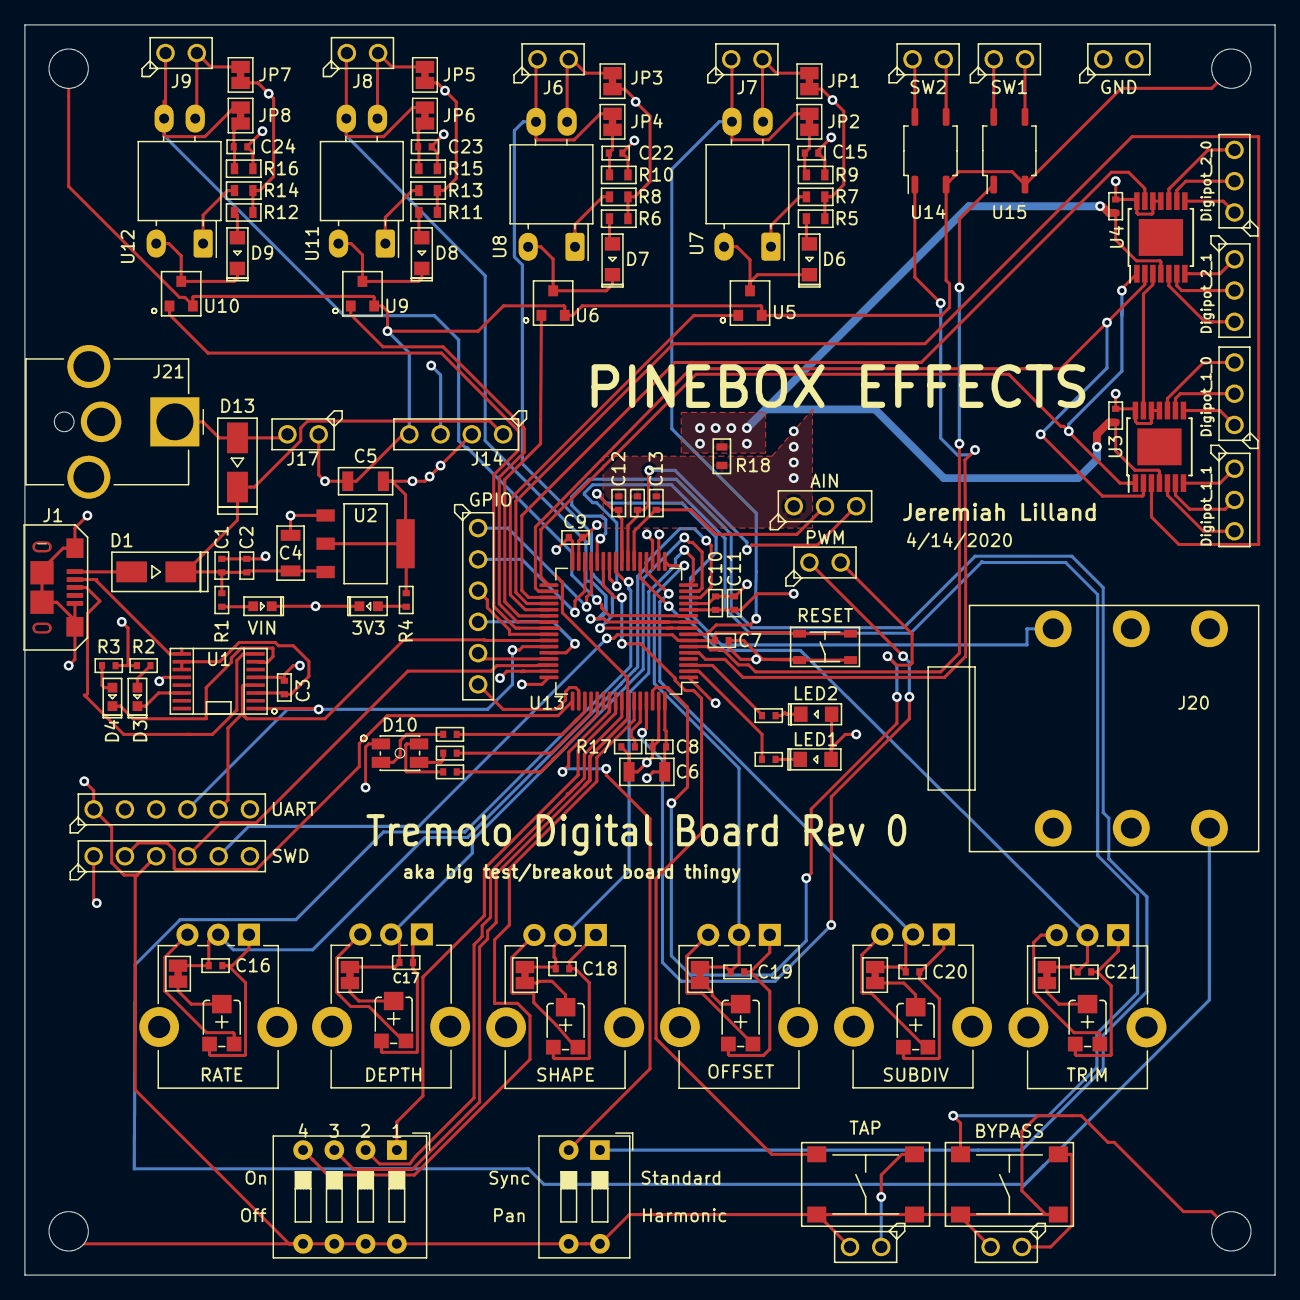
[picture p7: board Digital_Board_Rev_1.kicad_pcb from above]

Board: 4 copper layers, 101.6 x 101.6 mm, 133 parts (0 on the bottom side), 116 nets.

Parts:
3V3: LED_SINGLE-0603-GREEN; MF_LEDs-LED0603
AIN: CON_01X03_PTH_2.54MM; MF_Connectors-PTH_2.54MM_01X03
BYPASS: TACT_6MM; MF_Switches-TACT6MM
C1, C11: 1uF; MF_Passives-C0402
C2, C3, C7, C8, C9, C12, C13, C14, C16, C17, C18, C19, C20, C21: 0.1uF; MF_Passives-C0402
C4, C5, C6: 10uF; MF_Passives-C1206
C10: 10n; MF_Passives-C0402
C15, C22, C23, C24: 100n; MF_Passives-C0402
D1, D13: DIODES_B140_SMA; MF_Discrete_Semiconductor-SMA
D3, D4: LED_SINGLE-0603-GREEN; MF_LEDs-LED0603
D6, D7, D8, D9: LED_SINGLE-0805-RED; MF_LEDs-LED0805
D10: LED_RGB_CA_PLCC4; MF_LEDs-PLCC4
DEPTH: POTENTIOMETER_10K_TC33; MF_Passives-TC33
Digipot_1_0, Digipot_1_1, Digipot_2_0, Digipot_2_1: CON_01X03_PTH_2.54MM; MF_Connectors-PTH_2.54MM_01X03
GND: VAL**; MF_Connectors-PTH_2.54MM_01X02
GPIO: CON_01X06_PTH_2.54MM; MF_Connectors-PTH_2.54MM_01X06
H1, H2, H3, H4: MountingHole_Pad; MountingHole_3.2mm_M3
J1: USB_MICRO_RIGHT; MF_Connectors-MICROUSB-RIGHT
J6, J7, J8, J9: Conn_01x02_Male; MF_Connectors-PTH_2.54MM_01X02
J13, J17, J22: CON_01X02_PTH_2.54MM; MF_Connectors-PTH_2.54MM_01X02
J14: CON_01X04_PTH_2.54MM; MF_Connectors-PTH_2.54MM_01X04
J20: AudioJack3_Switch; Jack_0.25in_TRS_Switched
J21: Barrel_Jack; BarrelJack_CUI_PJ-063AH_Horizontal_CircularHoles
JP1, JP2, JP3, JP4, JP5, JP6, JP7, JP8, JP9, JP10, JP11, JP12, JP13, JP14: SolderJumper_2_Bridged; SolderJumper-2_P1.3mm_Bridged_Pad1.0x1.5mm
LED1: LED_SINGLE-0805-GREEN; MF_LEDs-LED0805
LED2: LED_SINGLE-0805-RED; MF_LEDs-LED0805
OFFSET: POTENTIOMETER_10K_TC33; MF_Passives-TC33
PWM: CON_01X02_PTH_2.54MM; MF_Connectors-PTH_2.54MM_01X02
R1: 560; MF_Passives-R0402
R2, R3: 330; MF_Passives-R0402
R4: 470; MF_Passives-R0402
R5, R6, R7, R8, R11, R12, R13, R14: 100; MF_Passives-R0603
R9, R10, R15, R16: 10k; MF_Passives-R0603
R17: 10k; MF_Passives-R0402
R18: 0; MF_Passives-R0603
R25, R26, R27: 100; MF_Passives-R0402
R28, R29: 47; MF_Passives-R0402
RATE: POTENTIOMETER_10K_TC33; MF_Passives-TC33
RESET: TACT_4.2MM; MF_Switches-TACT4.2MM
RV1, RV2, RV3, RV4, RV5, RV6: 10k; Potentiometer_Alpha_RD901F-40-00D_Single_Vertical_CircularH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
SHAPE: POTENTIOMETER_10K_TC33; MF_Passives-TC33
SUBDIV: POTENTIOMETER_10K_TC33; MF_Passives-TC33
SW1, SW2: CON_01X02_PTH_2.54MM; MF_Connectors-PTH_2.54MM_01X02
SW1#2: SW_DIP_x04; SW_DIP_SPSTx04_Slide_9.78x12.34mm_W7.62mm_P2.54mm
SW2#2: SW_DIP_x02; SW_DIP_SPSTx02_Slide_9.78x7.26mm_W7.62mm_P2.54mm
SWD: CON_01X06_PTH_2.54MM; MF_Connectors-PTH_2.54MM_01X06
TAP: TACT_6MM; MF_Switches-TACT6MM
TRIM: POTENTIOMETER_10K_TC33; MF_Passives-TC33
U1: FT230XS-R; MF_IC_Digital-SSOP16
U2: NCP1117LPST33T3G; MF_IC_Power-SOT-223-3
U3, U4: MCP42050; TSSOP-14-1EP_4.4x5mm_P0.65mm
U5, U6, U9, U10: NPN_BJTMMBT3904_SOT-23-3; MF_Discrete_Semiconductor-SOT-23-3
U7, U8, U11, U12: NSL-32; Luna_NSL-32
U13: STM32F030RCTx; LQFP-64_10x10mm_P0.5mm
U14, U15: CPC1017N; SOP-4_3.8x4.1mm_P2.54mm
UART: CON_01X06_PTH_2.54MM; MF_Connectors-PTH_2.54MM_01X06
VIN: LED_SINGLE-0603-GREEN; MF_LEDs-LED0603

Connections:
+3V3: C5.1, C6.1, C8.1, C9.1, C10.1, C11.1, D10.1, DEPTH.3, J14.2, J20.R, JP1.1, JP3.1, JP5.1, JP7.1, LED1.ANOD, LED2.ANOD, OFFSET.3, R2.1, R3.1, R4.1, R5.1, R6.1, R7.1, R8.1, R11.1, R12.1, R13.1, R14.1, RATE.3, RV1.3, RV2.3, RV3.3, RV4.3, RV5.3, RV6.3, SHAPE.3, SUBDIV.3, SWD.1, TRIM.3, U1.12, U2.1, U2.3, U3.11, U3.12, U3.14, U4.11, U4.12, U4.14, U13.1, U13.13, U13.19, U13.32, U13.48, U13.64
+9V: D13.ANOD, J17.2, J21.1
/Digipots/CS: U3.1, U4.1, U13.33
/Digipots/SCK: U3.2, U4.2, U13.34
/Digipots/SI: U4.13, U13.35
/Digipots/SO: U3.3, U13.36
/Digipots/SO1_SI2: U3.13, U4.3
/MCU/BYPASS: BYPASS.1, U13.26
/MCU/DEPTH: C17.1, JP10.1, RV2.2, U13.15
/MCU/EXP: C12.1, J20.T, U13.24
/MCU/EXP_SW: J20.SN, U13.25
/MCU/GPIO_1: GPIO.1, U13.29
/MCU/GPIO_2: GPIO.2, U13.30
/MCU/GPIO_3: GPIO.3, U13.41
/MCU/GPIO_4: GPIO.4, U13.44
/MCU/GPIO_5: GPIO.5, U13.45
/MCU/GPIO_6: GPIO.6, U13.50
/MCU/GP_AIN1: AIN.2, C13.1, U13.22
/MCU/GP_AIN2: AIN.3, C14.1, U13.23
/MCU/GP_PWM1: PWM.1, U13.61
/MCU/GP_PWM2: PWM.2, U13.62
/MCU/LDRV_1: J7.1, JP2.1, U7.3, U13.8
/MCU/LDRV_2: J6.1, JP4.1, U8.3, U13.9
/MCU/LDRV_3: J8.1, JP6.1, U11.3, U13.10
/MCU/LDRV_4: J9.1, JP8.1, U12.3, U13.11
/MCU/NRST: C7.1, RESET.1, RESET.2, SWD.5, U13.7
/MCU/OFFSET: C19.1, JP12.1, RV4.2, U13.17
/MCU/PWM1: U5.1, U13.37
/MCU/PWM2: U6.1, U13.38
/MCU/PWM3: U9.1, U13.39
/MCU/PWM4: U10.1, U13.40
/MCU/RATE: C16.1, JP9.1, RV1.2, U13.14
/MCU/RXD: U1.1, U13.43, UART.4
/MCU/SHAPE: C18.1, JP11.1, RV3.2, U13.16
/MCU/SUBDIV: C20.1, JP13.1, RV5.2, U13.20
/MCU/SW1_1: SW2.1, U14.4
/MCU/SW1_2: SW2.2, U14.3
/MCU/SW1_CTL: U13.5, U14.1
/MCU/SW2_1: SW1.1, U15.4
/MCU/SW2_2: SW1.2, U15.3
/MCU/SW2_CTL: U13.6, U15.1
/MCU/SWCLK: SWD.2, U13.49
/MCU/SWDIO: SWD.4, U13.46
/MCU/TAP: TAP.1, U13.27
/MCU/TRIM: C21.1, JP14.1, RV6.2, U13.21
/MCU/TXD: U1.4, U13.42, UART.5
/Power_USB/USBDM: J1.2, U1.9
/Power_USB/USBDP: J1.3, U1.8
GNDA: AIN.1, C10.2, C11.2, C12.2, C13.2, C14.2, C15.2, C16.2, C17.2, C18.2, C19.2, C20.2, C21.2, C22.2, C23.2, C24.2, DEPTH.1, GND.1, GND.2, J14.3, J20.S, OFFSET.1, R9.2, R10.2, R15.2, R16.2, R18.1, RATE.1, RV1.1, RV2.1, RV3.1, RV4.1, RV5.1, RV6.1, SHAPE.1, SUBDIV.1, TRIM.1, U13.12
GNDD: 3V3.CATH, BYPASS.3, BYPASS.4, C1.2, C2.2, C3.2, C4.2, C5.2, C6.2, C7.2, C8.2, C9.2, H1.1, H2.1, H3.1, H4.1, J1.5, J1.S1, J1.S2, J1.S3, J1.S4, J1.S5, J1.S6, J13.2, J14.4, J17.1, J21.2, J22.2, R17.2, R18.2, RESET.3, RESET.4, SW1#2.5, SW1#2.6, SW1#2.7, SW1#2.8, SW2#2.3, SW2#2.4, SWD.3, TAP.3, TAP.4, U1.5, U2.2, U3.4, U4.4, U5.2, U6.2, U9.2, U10.2, U13.18, U13.31, U13.47, U13.63, U14.2, U15.2, UART.1, VIN.CATH
unnamed: C3.1, U1.3, U1.10, U1.11
unnamed: C15.1, JP2.2, R9.1
unnamed: C22.1, JP4.2, R10.1
unnamed: C23.1, JP6.2, R15.1
unnamed: C24.1, JP8.2, R16.1
unnamed: D1.ANOD, J1.1
unnamed: R1.2, VIN.ANOD
unnamed: D3.ANOD, R2.2
unnamed: D3.CATH, U1.14
unnamed: D4.ANOD, R3.2
unnamed: D4.CATH, U1.7
unnamed: 3V3.ANOD, R4.2
unnamed: D6.ANOD, R5.2
unnamed: D6.CATH, U5.3, U7.2
unnamed: D7.ANOD, R6.2
unnamed: D7.CATH, U6.3, U8.2
unnamed: D8.ANOD, R11.2
unnamed: D8.CATH, U9.3, U11.2
unnamed: D9.ANOD, R12.2
unnamed: D9.CATH, U10.3, U12.2
unnamed: D10.2, R27.2
unnamed: D10.3, R28.2
unnamed: D10.4, R29.2
unnamed: LED1.CATH, R25.2
unnamed: LED2.CATH, R26.2
unnamed: Digipot_1_0.1, U3.8
unnamed: Digipot_1_0.2, U3.9
unnamed: Digipot_1_0.3, U3.10
unnamed: Digipot_1_1.1, U3.7
unnamed: Digipot_1_1.2, U3.6
unnamed: Digipot_1_1.3, U3.5
unnamed: Digipot_2_0.1, U4.8
unnamed: Digipot_2_0.2, U4.9
unnamed: Digipot_2_0.3, U4.10
unnamed: Digipot_2_1.1, U4.7
unnamed: Digipot_2_1.2, U4.6
unnamed: Digipot_2_1.3, U4.5
unnamed: J6.2, JP3.2, U8.4
unnamed: J7.2, JP1.2, U7.4
unnamed: J8.2, JP5.2, U11.4
unnamed: J9.2, JP7.2, U12.4
unnamed: BYPASS.2, J13.1
unnamed: J22.1, TAP.2
unnamed: JP9.2, RATE.2
unnamed: DEPTH.2, JP10.2
unnamed: JP11.2, SHAPE.2
unnamed: JP12.2, OFFSET.2
unnamed: JP13.2, SUBDIV.2
unnamed: JP14.2, TRIM.2
unnamed: R7.2, U7.1
unnamed: R8.2, U8.1
unnamed: R13.2, U11.1
unnamed: R14.2, U12.1
unnamed: R17.1, U13.60
unnamed: R25.1, U13.2
unnamed: R26.1, U13.3
unnamed: R27.1, U13.51
unnamed: R28.1, U13.52
unnamed: R29.1, U13.53
unnamed: SW1#2.1, U13.56
unnamed: SW1#2.2, U13.57
unnamed: SW1#2.3, U13.58
unnamed: SW1#2.4, U13.59
unnamed: SW2#2.1, U13.28
unnamed: SW2#2.2, U13.55
VBUS: C1.1, C2.1, C4.1, D1.CATH, D13.CATH, J14.1, R1.1, U2.4

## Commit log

2019-07-07 First commit. Schematic done?
    [Analog.SchDoc, Bypass.SchDoc, MASTER.SchDoc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]
2019-07-14 commit test
    Multiline?
    [Analog.SchDoc, Bypass.SchDoc, PCB1.PcbDoc]
2020-05-26 Started analog board schematic. Added SPICE files
    [10kPot.sch, 1590BB.stp, AnalogBoard_Rev0.kicad_pcb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]
2020-10-04 analog board done awhile ago lol
    [AnalogBoard_Rev0-BOT_Cu.gbr, AnalogBoard_Rev0-B_Mask.gbr, AnalogBoard_Rev0-B_SilkS.gbr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]
2021-11-07 r2 boards released, finally pushing
    [10kPot.sch, AnalogBoard_Rev0.sch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]
2023-06-14 reorg pt 1
    Reorganizing, deleted a bunch of stuff. Probably will reorg some more
    [Analog.SchDoc, AnalogBoard_Rev0.kicad_sch, AnalogBoard_Rev2.kicad_pcb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]
2023-06-14 moved everything out of Boards folder
    [10kPot.sch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]
2025-03-27 Added projects for V3 boards
    Made V3 projects, started with a few changes in both schematics.
    Migrated to KiCad 9.0.
    Repo needs a bit of reorg
    [10kPot.kicad_sch, AnalogBoard_Rev2.kicad_sch, AnalogBoard_Rev3.kicad_pcb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]
2025-03-27 Update .gitignore
    to exclude Kicad files
2025-03-27 Removed unnecessary files, added old gerber outputs
    Updated repo to remove files now ignored by updated .gitignore file.
    [1590BB.stp, AnalogBoard_Rev0.csv, AnalogBoard_Rev3.kicad_sch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]
2025-03-27 Moved all projects into "Rev_X/" folders
    [10kPot.kicad_sch, 10kPot.sch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]
